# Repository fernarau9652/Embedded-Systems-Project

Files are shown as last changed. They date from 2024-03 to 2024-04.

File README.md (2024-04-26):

# Digital and Analog Synthesizer with adjustable Frequency Scaling
ECE 5780/6780 Mini-Project for SPRING 2024 \
Team Members: Chase Griswold (6780), Fernando Araujo (6780), Alex Baret (5780), Vincent Banh (5780)

Official Documentation with wire diagrams, schematics, and flow charts can be found here (NOTE: Figures mentioned in the README pertain to the figures in the documentation listed): \
./Documentation/6780_CircuitDesign_DDS_REV-A_Final.pdf

This is the path to the finalized project folder for this project: \
./STM32/5780-6780-Final-Project3/  (Other files are previous revisions of the project)

Documentation related to the PCB designs with BoM datasheets can be found here: \
./PCB/  ("Board EXPORTS" contain the PCB design revisions; everything else is datasheets and LBR files)

Additional code provided by Chase can be found here: \
./Chase_Mains/  (Contains code for ADC and I2C control for digital potentiometer)

## Overview
The purpose of this project is to develop a digital and analog synthesizer machine that would take both types of inputs to output a modified synthesized wave, which can be used for voice modelization in further developments of this project. \
Our goals were to utilize various embedded system applications such as:
- Designing two custom PCBs that allow for signal generation and frequency oscillator modulation using physical and digital potentiometers.
- The signal generation PCB generates three analog signals: Square, Triangle, and Sine waves. By adjusting the physical potentiometer, the signal's frequency can be adjusted.
- The frequency oscillator PCB generates a square wave, whose frequency can be adjusted via the I2C digital potentiometer or photoresistor (the photoresistor was extra but cool to have).
- Implementing ADC through the signal generation PCB, sampling each signal through the STM32, and outputting the waves through the Analog Discovery 2 (AD2) device.
- Implementing DAC by configuring the CubeMX project by instantiating timer 7 (TIM7) to clock at a sampling rate of 42 kHz, then using DMA to store the signal to be output again. In this section, we implemented signal addition synthesis to describe how the output signal would look like if two more signals were added to the initial wave.
- I2C and USART communication that changes a signal's frequency from the frequency oscillator PCB where the user interfaces with putty to change the resistance from the I2C digital potentiometer, therefore changing frequency. This section of the project accounts for frequency modulation.
- USART uses interrupts to wait for the user's numerical input (integers from 0 to 255), then delivers the commands to the MCU and out to the I2C-controlled digital potentiometer on the frequency oscillating wave.

Analog waveforms may be generated with two custom PCBs designed specifically for this project. One PCB generates a square wave with its frequency variation controlled via an I2C-controlled digital potentiometer. 

The other PCB is designed to emit analog waveforms and may be configured to generate a square wave, a triangle wave, or a sine wave using LM741 Operational Amplifiers. Waveforms from the second PCB may be sampled using the STM32's onboard ADC. 

Separate from the custom-PCB waveform generation, TIM7 (a timer onboard the STM32) consisting of a 16-bit auto-reload counter driven by a programmable
prescaler, a direct memory access controller (DMA onboard the STM32) used to perform programmable data transfers between memory-mapped peripherals, and a digital-to-analog converter (DAC onboard the STM32) have been utilized to implement digital signal synthesis.

#### Target Hardware Platform(s) ####
- STM32F072 MCU
- Function Generator PCB (Fig. 1)
- I2C Frequency Oscillator PCB (Fig. 3)
- FT232RL chip for USB/USART communication
#### Development Tools ####
- μVision Kiel IDE
- Diligent Waveforms 
#### Programming Languages ####
- C

## Features
- Output analog sine waves using TIM7, DMA, and DAC to PA4
- Square Wave Function Generator PCB that uses an LM324N and a DS18030 Digital Potentiometer
- Control the frequency of the I2C-controlled DS18030 Potentiometer through a PuTTy interface that communicates through USART
- Function Generator PCB utilizing LM741 Operational Amplifiers to generate square, triangle, and sine waves

## Getting Started
1) Acquire an ADC for waveform analysis
2) Diligent Waveforms 
3) USB/USART chip
4) μVision Kiel IDE
5) PuTTY
6) I2C Frequency Oscillator PCB (Fig. 4)
7) Function Generator PCB (Fig. 2)
8) Follow the test setup in Fig. 5 (NOTE: an additional connection from the PC to USART to STM32 is missing from the layout.)

### Installation
The STM32 pinout (Fig. 6):
- PB14 - SDA (I2C)
- PB13 - SCL (I2C)
- PB10 - TX (USART)
- PB11 - RX (USART)
- PC3 - 12-bit ADC input
- PA4 - 12-bit DAC output (forgot to add to the wire diagram)

Connect the TX pin to RX on your USB to TTL UART device and RX to TX. This enables serial console control of the project.\
The SDA and SCL must then be connected to the I2C digital potentiometer PCB's SDA and SCL pins. Pull-up resistors are not needed, as the board has built-in pull-ups.

Alternately, PA4 may be directly connected to an oscilloscope or output device to take advantage of the internal function generation of the project.

## Usage
Usage in all cases save for the UART-controlled digital potentiometer functionality is plug-and-play. There is no need for user input beyond physical adjustments of potentiometers or the operation of the photoresistor.

When operating over UART, the initial connection once the microcontroller has been reset will result in the message "Waiting for USART input. Please enter a number between 0 and 255." being printed to the terminal. This message is intended to be self-explanatory, and an input sanitation/verification system has been implemented to reject any other inputs beyond this range of values.

Due to an issue regarding the input system, it may occasionally be necessary to press the enter key multiple times to receive a response from the microcontroller. Only do this after entering the full value intended.

To use the function generator circuit,  connect an oscilloscope or an ADC to the respective op-amp that generates the desired waveform (square, sawtooth, sine).

To modulate a digital signal wave using additive synthesis, the code allows users to add two Sine waves of different frequencies, takes the average between the values, and then buffers the signals to the intended 12-bit resolution for the output. 

Users may adjust FREQ1 and FREQ2 to whatever musical note frequency they choose. The code will adjust the additive sine signals to the original output signal of 420 Hz and then output the final product through PA4. Images of sample waves simulated in this project can be seen here: \
./Documentation/DAC_waves/

## Architecture
The documentation listed above contains all architecture-related diagrams for this project. Design specifications for the PCBs, BoM, wire diagrams, schematics, and flow charts are also included.

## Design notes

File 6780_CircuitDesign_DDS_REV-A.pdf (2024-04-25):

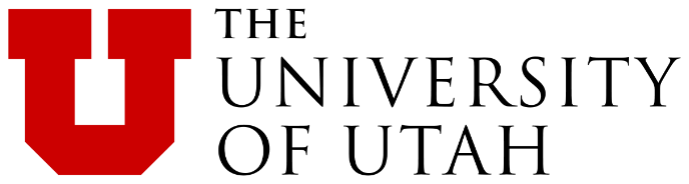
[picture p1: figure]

Chase Griswold. ECE 6780 - Embedded Systems, Spring 2024, University of Utah

### Document Stakeholders

(THESE NAMES ARE FOR INFORMATION ONLY)

PROGRAM / COURSE NUMBER

M.S. ECE: Embedded Systems 6780

Author | Chase Griswold

University of Utah

201 Presidents' Cir

Salt Lake City, Utah 84112

Design Engineer | Chase Griswold
Approver | Fernando Araujo
Approver | Vincent Banh
Approver | Alex Baret

BASELINE
Current

DATE
25 APR 2024

## Detailed Development Specification for the Function Generator and I2C Frequency Oscillator Circuits

Document: DDS | DDS for the Function Generator / I2C Frequency Oscillator
25 APR 2024 | Rev A | Page 2 of 20

This Page Intentionally Left Blank

25 APR 2024 | Rev A | Page 3 of 20
| | TABLE OF CONTENTS
Paragraph | Title | Page

25 APR 2024 | Rev - | Page 4 of 20

1 [-] INTRODUCTION

1.1 [-] Identification

This is a Detailed Development Specification document for the two PCBs/Circuits designed for the 6780 Embedded Systems final Project.
1) Function Generator Circuit Utilizing LM741 Operational Amplifiers.
2) Square Wave Function Generator Using LM324N and DS18030 Digital Potentiometer

1.2 [-] Function Generator (Overview)

This technical specification details the construction and operation of a function generator circuit that employs three LM741 operational amplifiers to produce square, triangle, and sine waveforms. The LM741 operational amplifier is a single, versatile, and reliable component used in various analog circuits, replacing the LM324 for this specific design. The circuit is capable of generating multiple waveforms with adjustments for frequency and amplitude, making it suitable for a wide range of applications. A schematic of the Function Generator can be seen in Figure 1.

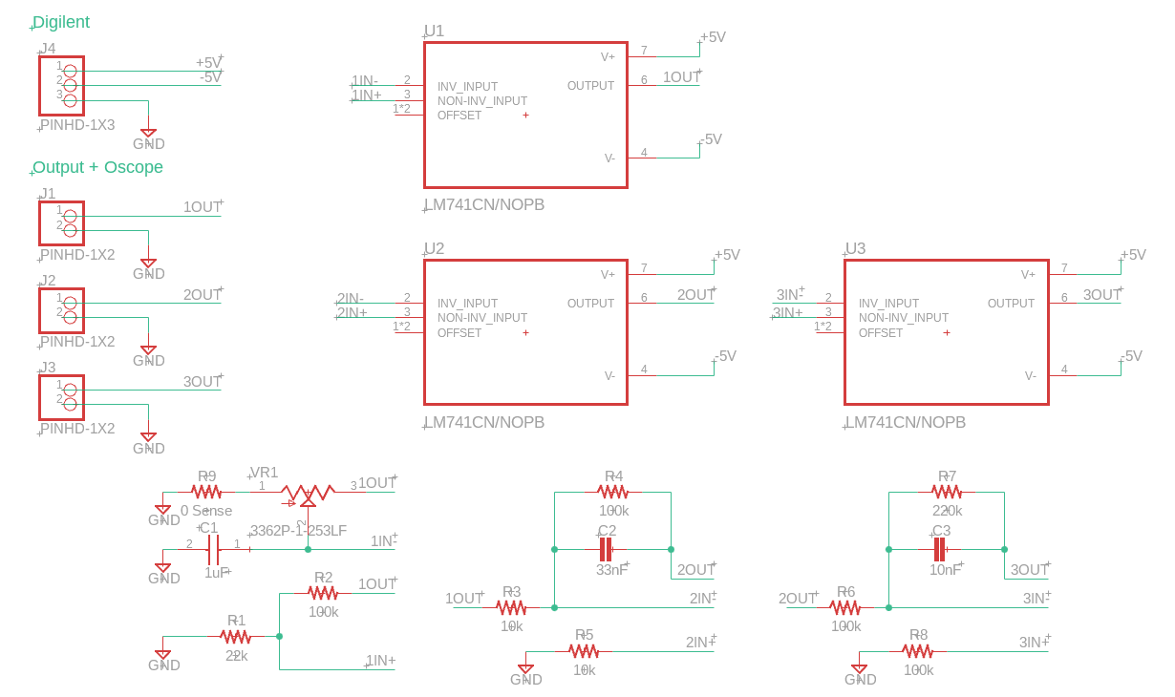
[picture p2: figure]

Figure 1 [-] Function Generator Circuit Utilizing LM741 Operational Amplifier

1.2.1 [-] External Interface Definition (Function Generator)

The PCB is shown in Figure 2, and the electrical interfaces are outlined in Table 1.

25 APR 2024 | Rev - | Page 5 of 20

Table 1 [-] Function Generator Electrical Interface

Module/CCA Ref Des | Connector Name | Connector Type | Mating Connector Type
J1 | Square Wave Output / GND | PINH Male | PINH Female
J2 | Triangle Wave Output / GND | PINH Male | PINH Female
J3 | Sine Wave Output / GND | PINH Male | PINH Female
J4 | ±5V Power Supply / GND | PINH Male | PINH Female

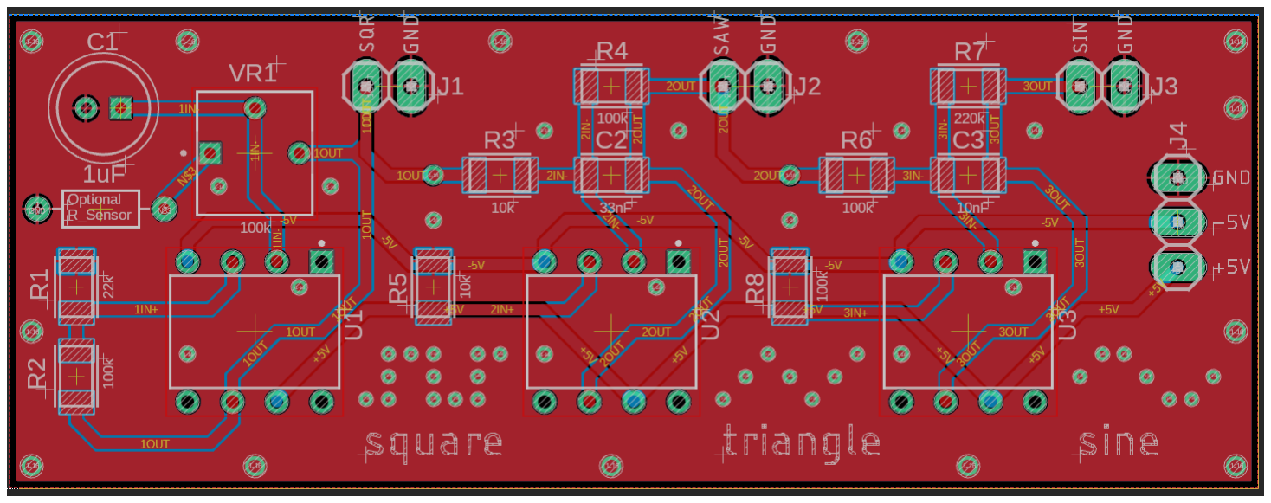
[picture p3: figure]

Figure 2 [-] Function Generator PCB

1.2.2 [-] Function Generator Operational Definitons

The LM741 operational amplifiers are biased with a dual-supply voltage of +5V and -5V, ensuring a broad signal swing range. The offset null pin of the LM741 is not utilized in this configuration. The first LM741 operational amplifier is configured to generate a square wave, which is then fed into a second LM741 configured as an integrator circuit to produce a triangle wave. This triangle wave is subsequently processed by another LM741 configured as an integrator circuit to output a sine wave. (Technically, the sine wave is formed of a parabolic voltage rise and fall, and then that parabolic voltage output is inverted, so it’s not truly a continuous sine wave).

Power is supplied to the circuit through the LM741’s power supply pins, accommodating a range from +5V to +15V for the positive supply and -5V to -15V for the negative supply. This power configuration ensures sufficient operation of the circuit across its functionalities.

Frequency modulation is achieved through a 100KΩ potentiometer, allowing for user control over the output signal's frequency. This potentiometer, in conjunction with the specific resistor and capacitor values, provides a wide range of frequency adjustments, emulating the flexibility of a standard function generator.

Amplitude adjustment can be easily implemented by varying the voltage from the DC power supply or, if powered by batteries, by adding a small-valued potentiometer (200Ω-500Ω) for voltage adjustment. This feature enhances the circuit's utility by allowing for precise control over the signal amplitude, accommodating various testing and measurement needs.

In summary, this function generator circuit, designed with LM741 operational amplifiers, offers the generation of square, triangle, and sine waveforms with adjustable frequency and amplitude. The circuit's design and component selection cater to a an excellent educational tool when considering the addition of probing points for each waveform, whereby they can be output onto an oscilloscope or sampled with an ADC.

25 APR 2024 | Rev - | Page 6 of 20

1.2.3 [A] Function Generator BOM

Table 2 [A] Function Generator BOM
Value | Type | QTY | NOTES
LM741 | IC (Amplifier) | 3
10KΩ | Resistor SMD | 2
100KΩ | Resistor SMD | 4
22KΩ | Resistor SMD | 1
220KΩ | Resistor SMD | 1
1μF | Capacitor Polarized Through-Hole | 1
1uF (REV A CHANGE) | Capacitor SMD | 1
100nF (REV A CHANGE) | Capacitor SMD | 1
N/A | PINHEADER | 10
100KΩ | Potentiometer | 1

1.3 [-] I2C Frequency Oscillator Overview

This technical specification details the construction and operation of an I2C controlled frequency oscillator circuit that employs an LM324N operational amplifier to produce a square waveform whose frequency can be adjusted via an I2C interfaced Digital Potentiometer (DS18030-100+). This is ostensibly a simpler take on the Function Generator circuit described in Section 1.2, where the potentiometer on that circuit is replaced with the DS18030-100+ I2C digital potentiometer and only the square wave is generated. A schematic of the I2C Frequency Oscillator can be seen in Figure 3.

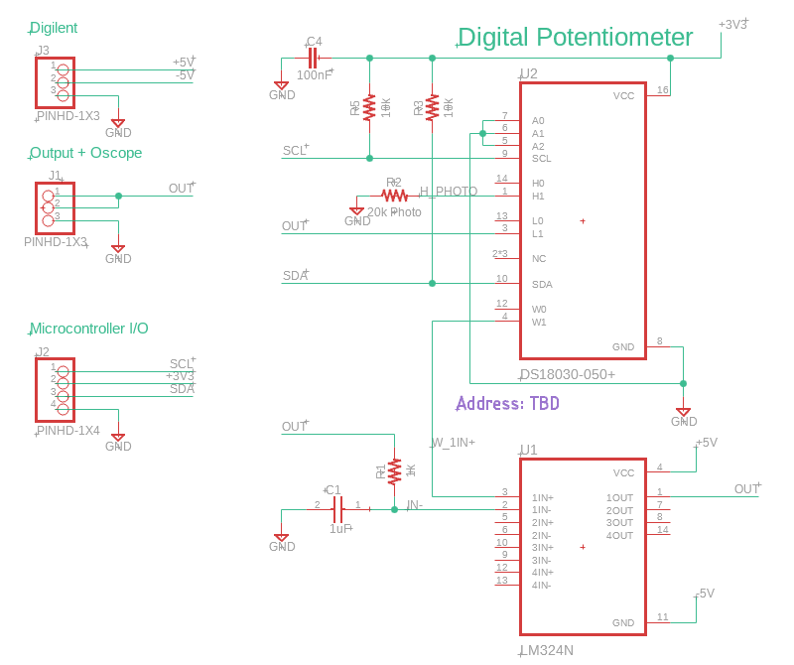
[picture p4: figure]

Figure 3 [-] I2C Frequency Oscillator Schematic

25 APR 2024 | Rev - | Page 7 of 20

1.3.1 [-] External Interface Definition (I2C Frequency Oscillator)

The I2C Frequency Oscillator PCB is shown in Figure 4, and the electrical interfaces are outlined in .

Table 3 [-] I2C Frequency Oscillator Electrical Interfae

Module/CCA Ref Des | Connector Name | Connector Type | Mating Connector Type
J1 | Square Wave Output / GND | PINH Male | PINH Female
J2 | I2C CMD/STS – V / GND | PINH Male | PINH Female
J3 | ±5V Power Supply / GND | PINH Male | PINH Female

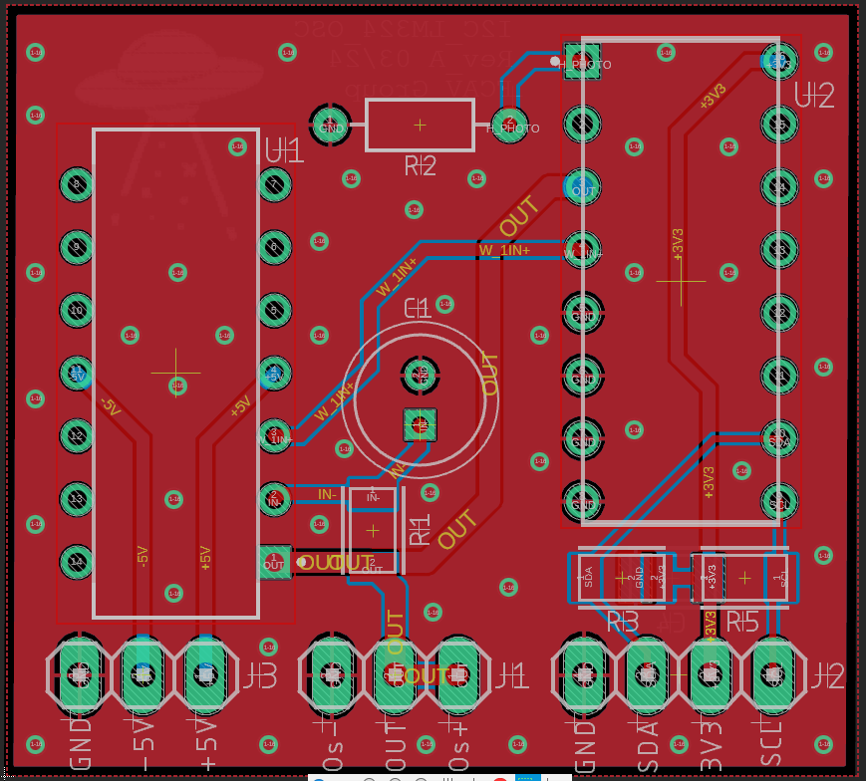
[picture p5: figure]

Figure 4 [-] I2C Frequency Oscillator PCB

25 APR 2024 | Rev - | Page 8 of 20

### 1.3.2 I2C Frequency Oscillator Operational Definitons

The circuit employs one operational amplifier within the LM324N chip to generate the square wave. Power is supplied to the LM324N with +5V and -5V to ensure a broad output swing. The frequency adjustment is facilitated by the DS18030-100+ digital potentiometer, which offers 256 tap points over a 100KΩ range, allowing for fine-tuning of the square wave's frequency. This digital potentiometer is controlled via an I2C interface, providing a way to adjust the function generator's output without manual intervention.

1.3.3 [-] I2C Frequency Oscillator BOM

Table 4 [-] I2C Frequency Oscillator BOM
Value | Type | QTY | NOTES
LM324N | IC/Amplifier | 1
DS18030-100+ | IC/ Digital Potentiometer | 1
10KΩ | Resistor | 2
1KΩ | Resistor | 1
20KΩ | Photo Resistor | 1 | optional
220KΩ | Resistor | 1
1μF | Capacitor / Polarized Through-Hole | 1
100nF | Capacitor / SMD | 1
100KΩ | Potentiometer | 1

1.4 [-] Referenced Items

Table 5 [-] Referenced Items

Document | Title
LM324N | Datasheet
LM741 | Datasheet
DS18030-100+ | Datasheet

25 APR 2024 | Rev - | Page 9 of 20

2 [-] TEST RESOURCES AND SETUP

2.1 [-] Test Resources

Table 6 lists the needed resources (or equivalent) for completing the design and scope of this part of the project. An STM32 Discovery Kit provides a versatile development platform for prototyping and testing the designs. Keil µVision IDE is an essential tool for writing, compiling, and debugging the microcontroller code, offering a user-friendly interface and powerful features that streamline the development process. To complement these resources, the Digilent Analog Discovery 2 serves as an invaluable tool for analyzing the electrical characteristics of the circuits. This multi-function instrument can act as an oscilloscope, function generator, power supply, and more.

Table 6 [-] Test Resources
Name | Model | Description | Qty | Manufacturer | Notes
Digilent Analog Discovery 2 | 2 | Signal/Logic Analyzer, Power Supply | 1 | Digilent
STM32 discovery kit STM32F072x8/xB | STM32F07 2x8/xB | Embedded Systems Application Development Board | 1 | STMicroelectronics
Keil µVision IDE | | IDE for programming the microcontroller | | Keil
PC | | Standard Issue Lab PC | 1
Misc. Cables | Various | Power/CMD/STS/Oscill oscope | | | Cables as needed
Misc. Hardware | Various | Multi-meter, etc… | | | General lab items as needed

2.2 [A] Test Setup

Connect the PCBs to the STM32 and Digilent AD2 in accordance with (IAW) Figure 5.

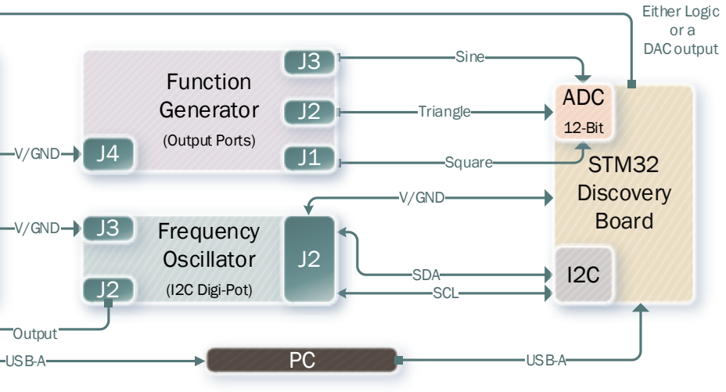
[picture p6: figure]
STM32 Discovery Board Frequency; Oscillator; (I2C Digi-Pot); Sine; SDA SCL; Square; ADC; 12-Bit; Function Generator; (Output Ports); Triangle; Either Logic or a DAC output; Output; V/GND; USB-A

Figure 5 [-] Test Setup for the Circuit Design Portion

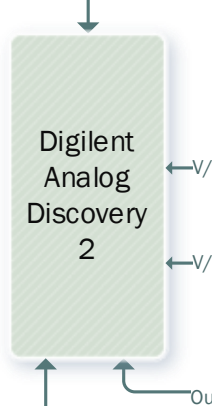
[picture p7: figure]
Digilent Analog Discovery 2
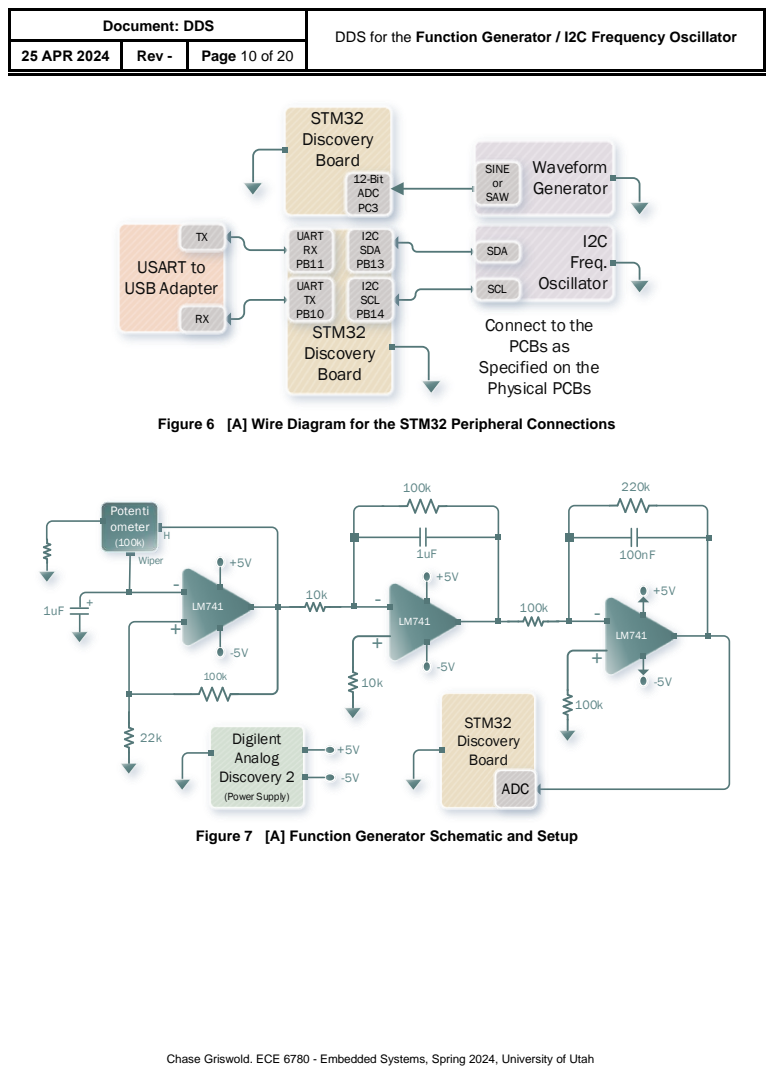
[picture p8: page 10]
25 APR 2024; Rev -; Page 10 of 20; STM32 Discovery Board; I2C SDA PB13; 12-Bit ADC PC3; I2C SCL PB14; I2C Freq. Oscillator; UART RX PB11; UART TX PB10; USART to USB Adapter; Waveform Generator; SDA; SCL; SINE or SAW; Potenti ometer; Wiper; Digilent Analog Discovery 2; (Power Supply); ADC

Connect to the
PCBs as
Specified on the
Physical PCBs

Figure 6 [A] Wire Diagram for the STM32 Peripheral Connections

Figure 7 [A] Function Generator Schematic and Setup

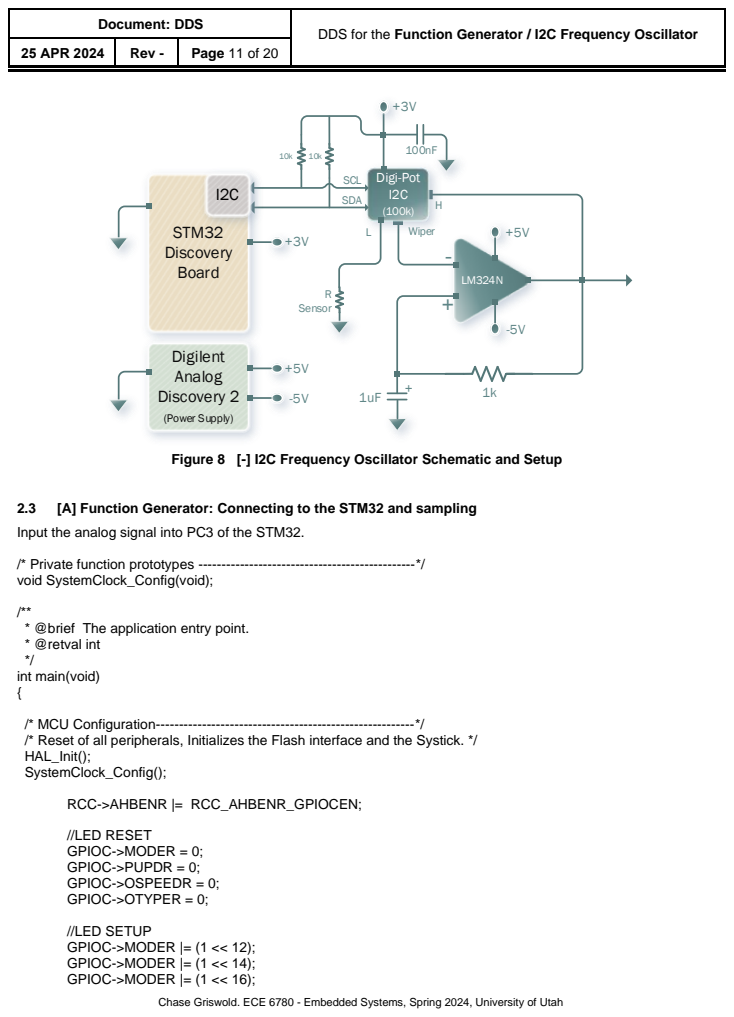
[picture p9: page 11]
25 APR 2024; Rev -; Page 11 of 20; SCL; SDA; Digi-Pot I2C; Wiper; R Sensor; Digilent Analog Discovery 2; (Power Supply); RCC->AHBENR |= RCC_AHBENR_GPIOCEN;; //LED RESET GPIOC->MODER = 0; GPIOC->PUPDR = 0; GPIOC->OSPEEDR = 0; GPIOC->OTYPER = 0;; //LED SETUP GPIOC->MODER |= (1 << 12); GPIOC->MODER |= (1 << 14); GPIOC->MODER |= (1 << 16);

STM32
Chase Griswold. ECE 6780 - Embedded Systems, Spring 2024, University of Utah +5V
Discovery
Board

Figure 8 [-] I2C Frequency Oscillator Schematic and Setup

2.3 [A] Function Generator: Connecting to the STM32 and sampling
Input the analog signal into PC3 of the STM32.

/* Private function prototypes -----------------------------------------------*/
void SystemClock_Config(void);

* @brief The application entry point.
* @retval int
int main(void)

/* MCU Configuration--------------------------------------------------------*/
/* Reset of all peripherals, Initializes the Flash interface and the Systick. */
HAL_Init();
SystemClock_Config();

25 APR 2024 | Rev - | Page 12 of 20

GPIOC->MODER |= (1 << 18);

//Set GPIOC low
GPIOC->ODR = 0;

//Set PC3 to Analog mode. (Connects to ADC_IN13) GPIOC->MODER |= (3 << 6);

// Enable the ADC1 in the RCC peripheral.
RCC->APB2ENR |= RCC_APB2ENR_ADCEN;

//Configure the ADC to 8-bit resolution, continuous conversion mode, hardware triggers //disabled (software trigger only).
ADC1->CFGR1 = 0; //Clear: Also Disables Hardware Triggers
ADC1->CFGR1 |= (1 << 13); //Continuous Conversion Mode
ADC1->CFGR1 |= (0 << 3);
ADC1->CFGR1 |= (0 << 4); //12-Bit Resolution

// Select/enable the input pin s channel for ADC conversion ADC1->CHSELR = 0; //Clear
ADC1->CHSELR |= (1 << 13); //Set Channel to ADC_IN13

// Perform a self-calibration, enable, and start the ADC. ADC1->CR = 0; //Cal
ADC1->CR |= (1 << 31); //Enable

//Wait: ADCAL: ADC calibration bit 31 = 0
while (((ADC1->CR)>>31) != 0){

}

//Zero out the ADEN
ADC1->CR |= (1 << 0); //Set ADEN

//Wait ADRDY Flag
while((ADC1->ISR && 0x1) != 1){ //ISR Bit 0: ADRDY }

//Set ADSTART: Start Conversion
ADC1->CR |= (1 << 2);

uint16_t reso = 0;

/* Infinite loop */

while (1)

{

//12-bit ADC - 4096 bits of resolution/4 LEDs = 1024

//RED 6, BLUE 7, ORANGE 8, GREEN 9

//Apply the DR stored value to a variable that can be used in the loop.

reso = ADC1->DR;

if (reso < 1024){

25 APR 2024 | Rev - | Page 13 of 20
| | GPIOC->ODR |= (1 << 6); //Red High
| | GPIOC->ODR &= ~((1 << 7) | (1 << 8) | (1 << 9));

}

else if (reso >= 1024 && reso < 2048){

| | GPIOC->ODR |= (1 << 7); // Blue High
| | GPIOC->ODR &= ~((1 << 8) | (1 << 9));

}

else if (reso >= 2048 && reso < 3072){

| | GPIOC->ODR |= (1 << 8); //Orange High
| | GPIOC->ODR &= ~(1 << 9);

}

| else {
| | GPIOC->ODR |= (1 << 9); //Green High

}

//Wait: End Sequence

while((ADC1->ISR & 0x4) != 4){

}

//Reset: FLAG after each loop

ADC1->ISR |= (1 << 2);

}

}

2.4 [A] I2C Frequency Oscillator: I2C Control with STM32

NOTE: The code below uses PB11 and PB13 for SDA and SCL respectively, versus the USART version in the wire diagram where PB11 is changed to PB14.

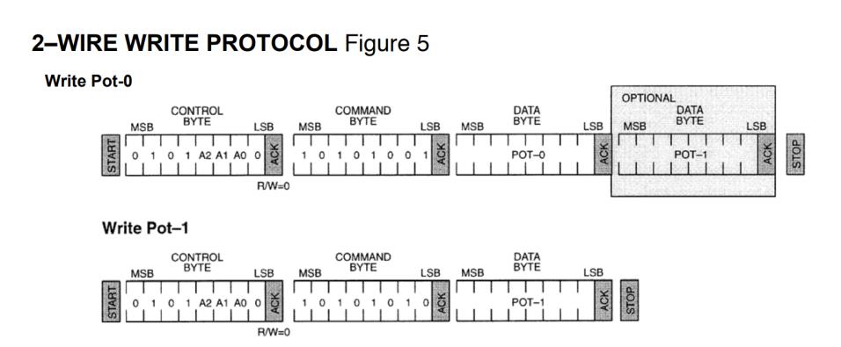
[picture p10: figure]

The PCB is hooked up to Pot-1,
USART TX from PUTTY sets the DATA BYTE values when performing the write command.

25 APR 2024 | Rev - | Page 14 of 20

Below is a simple implementation of writing to the i2c controlled Digi-Pot.

/* Includes ------------------------------------------------------------------*/
#include "main.h"

/* Private function prototypes -----------------------------------------------*/ void SystemClock_Config(void);
/* USER CODE BEGIN */

//void init_digiPot(void); //For hardcode Data Byte Version
void init_digiPot(int c);
uint8_t resist_val_data;
volatile uint8_t data;

/**
* @brief The application entry point. * @retval int
*/
int main(void)
{
/* Reset of all peripherals, Initializes the Flash interface and the Systick. */ HAL_Init();
SystemClock_Config();

/* USER CODE BEGIN SysInit */
//Enable GPIOB and GPIOC
RCC->AHBENR |= RCC_AHBENR_GPIOCEN;
RCC->AHBENR |= RCC_AHBENR_GPIOBEN; //Needed for I2C stuff

//Initialize (Clear) the GPIOB/C registers
GPIOB->OTYPER = 0;
GPIOB->MODER = 0;

//SDA Setup --------
//Initialize PB11
GPIOB->MODER |= (1 << 23); //Enable AF Mode GPIOB->OTYPER |= (1 << 11); //Open-drain

//PB11 Alternate Function AF1 select: I2C2_SDA -> AF1 of PB11 //Bits [15:12] correspond to PB11 in the register -> AF1 is 0001. GPIOB->AFR[1] |= (1 << 12);

//SCL Setup --------
// Initialize PB13
GPIOB->MODER |= (1 << 27); //Enable AF Mode GPIOB->OTYPER |= (1 << 13); //Open-drain

//PB13 Alternate Function AF5 select: I2C2_SCL -> AF5 of PB13 //Bits [23:20] correspond to PB13 in the register, -> AF5 is 0101. GPIOB->AFR[1] |= (5 << 20);

//Initialize PC0 and PB14
GPIOB->MODER |= (1 << 28); //General-Purpose Output GPIOC->MODER |= (1 << 0);
GPIOC->OTYPER = 0; //Push-pull mode.
GPIOB->ODR |= (1 << 14); //PB14 set High

25 APR 2024 | Rev - | Page 15 of 20

GPIOC->ODR |= (1 << 0); //PC0 set High

//I2C2 Peripheral RCC Enable (I2C)
RCC->APB1ENR |= RCC_APB1ENR_I2C2EN; //Clock enable

//Setting up the I2C2 Peripheral timing for SDA and SCL
//Set to 100kHz operation
I2C2->TIMINGR |= (1 << 28); //PSC = 1
I2C2->TIMINGR |= (0x4 << 20); //[23:20] SCLDEL (Data Setup Time) I2C2->TIMINGR |= (0x2 << 16); //[19:16] SDADEL (Data Hold Time) I2C2->TIMINGR |= (0xF << 8); //[15:8] SCLH (SCL High Period) I2C2->TIMINGR |= (0x13 << 0); //[7:0] SCLL (SCL Low Period)

//Enable the I2C2 Peripheral
I2C2->CR1 |= (1 << 0); //Enable (PE Bit in CR1 Register)

// Hardcodede version
//resist_val_data = 0b00010000; //Data Byte (256-bit resolution number, ~396 ohms per bit).
| data = 0;

// /* Infinite loop */ //Used to loop through all 0-255 Data Byte Values for simple visual results on an oscope.
| while (1)
{
| | init_digiPot(data); if(data<255) {

data++;
| | } else {

data = 0;
| | } HAL_Delay(25); // Delay 25ms GPIOC->ODR ^= (1 << 6);

}
}

//void write_digiPot() //If using the hardcoded version. void write_digiPot(int resist_val_data){
I2C2->CR2 = 0; //Clear to start.

//Setup: Digi-pot Address 0x28
I2C2->CR2 |= (0x28 << 1); //Digi-pot address is [7:1]

//Set # of bytes = 2 (Address + Register value). I2C2->CR2 |= (2 << 16);

//Set the RD_WRN bit to 'WRITE' operation. //Set the START bit
I2C2->CR2 &= ~(1 << 10); //Ensure 0 for write
I2C2->CR2 |= (1 << 13);

//Wait until either of the TXIS (Transmit Register Empty/Ready) //or NACKF (Slave NotAcknowledge) flags are set.

25 APR 2024 | Rev - | Page 16 of 20

//----//If the NACKF flag is set, the slave did not respond to the address frame. //----//Continue if the TXIS flag is set
while(((I2C2->ISR & 0x2) >> 1) != 1){
| | if((I2C2->ISR & 0x10) >> 4){ //NACFK flag check //Turn on LED to indicate config error GPIOC->ODR |= (1 << 6);

}
}

//Set command_byte for digi-pot TX
I2C2->TXDR = 0b10101010; // Command Byte to write to potentiometer 1.

//Wait for TXIS flag
while(((I2C2->ISR & 0x2) >> 1) != 1){
| | if((I2C2->ISR & 0x10) >> 4){ //NACFK flag check //Turn on LED to indicate config error GPIOC->ODR |= (1 << 6);

}
}

//Set data_byte for digi-pot TX I2C2->TXDR = resist_val_data;

//Wait for TC flag
while(((I2C2->ISR & 0x40) >> 6) != 1){

}

//STOP bit: Release the I2C bus I2C2->CR2 |= (1 << 14);
}

Where resist_val_data is some 8-bit value written to the Data Byte of the digital potentiometer, with each 0-255 step value corresponding to ~390 ohms out of 100k ohms.

25 APR 2024 | Rev - | Page 17 of 20

3 [-] COMPONENT DESCRIPTIONS

3.1 [-] Amplifiers

3.1.1 [-] LM741

The LM741 is a classic operational amplifier (op-amp) integrated circuit known for its versatile performance in analog circuit applications. Featuring a single op-amp configuration, it offers reliable amplification and signal processing capabilities. With its wide supply voltage range and compatibility with both single and dual power supplies, the LM741 is suitable for a variety of voltage requirements in different circuit designs. This IC comes in an 8-pin DIP package, making it easy to incorporate into various electronic projects. Its straightforward pinout and simple configuration make it a popular choice for amplification, filtering, and signal conditioning tasks in electronics.

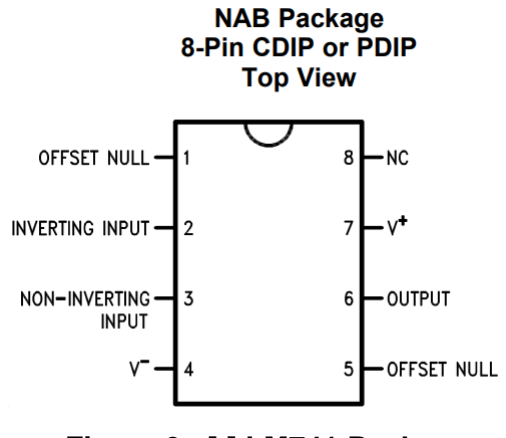
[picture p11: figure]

Figure 9 [-] LM741 Package

3.1.2 [-] LM324N

The LM324N is a widely used quad operational amplifier (op-amp) integrated circuit renowned for its versatility and reliability in analog circuit designs. With four independent op-amps housed within a single chip, it offers convenience and space-saving benefits for circuit integration. The LM324N operates over a wide range of supply voltages and is compatible with both single and dual power supplies, making it suitable for diverse voltage requirements. Its simple pinout and standard 14-pin DIP package facilitate easy incorporation into various electronic projects. Renowned for its low cost and robust performance, the LM324N is commonly utilized in amplification, filtering, signal conditioning, and other analog applications across industries.

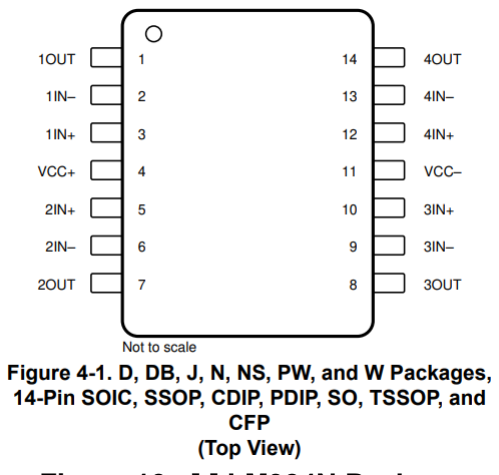
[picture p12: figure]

Figure 10 [-] LM324N Package

25 APR 2024 | Rev - | Page 18 of 20

3.2 [-] I2C

3.2.1 [-] Digital Potentiometer

Address: 0101000 (A2, A1, A0 tied to ground for the 000) - Hex: 0x28

The DS18030 is a digital potentiometer integrated circuit designed for electronic control applications. It features a 100 kΩ resistance with 256-tap resolution, allowing for precise adjustment in various circuits. This device utilizes a 2-wire serial interface, compatible with I2C communication protocols, facilitating easy integration with microcontrollers like the STM32. With its compact 16-pin DIP package, the DS18030 offers versatility and flexibility in analog circuit designs, providing a convenient solution for applications requiring digital potentiometer functionality.

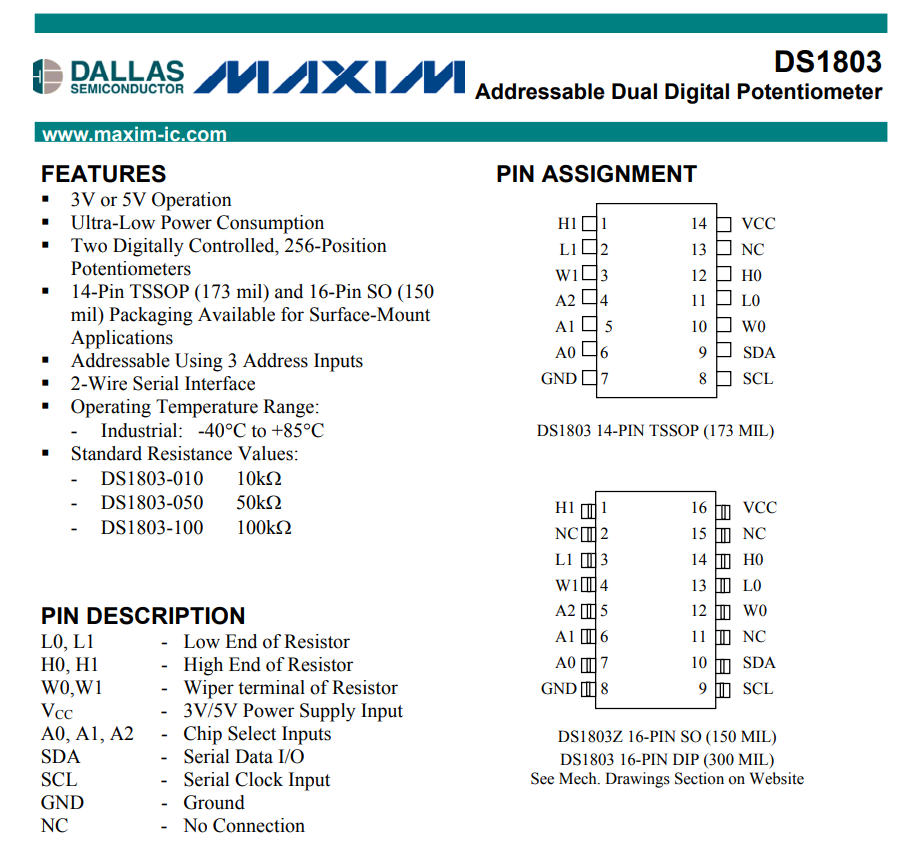
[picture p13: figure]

25 APR 2024 | Rev - | Page 19 of 20

4 [A] NOTES

We implemented an additional protocol to transmit the i2c Data Byte 8-bit digital potentiometer value over USART via PuTTY, essentially creating a GUI for us to change resistor values from.

We attached a photoresistor to the i2c Frequency Oscillator circuit to showcase how a resistive sensor can be applied to change the analog frequency, where different frequencies could correspond to different operations of a larger system. See “R-Sensor” in circuit diagram in the “setup” section.

25 APR 2024 | Rev - | Page 20 of 20

5 [-] REVISION HISTORY

Table 7 [-] Revision Table for DDS

Rev | Date | Engineer | Description
- | Mar 2023 | Chase Griswold | Initial Release
A | April 2023 | Chase Griswold | Revision A (changes to waveform generator capacitors, new schematic included in setup)

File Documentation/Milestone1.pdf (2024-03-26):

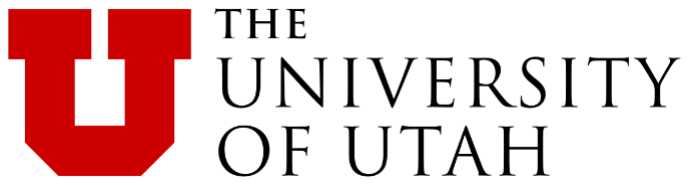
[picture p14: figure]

Chase Griswold, Fernando Araujo, Alex Baret, Vincent Banh. ECE 6780 - Embedded Systems, Spring 2024, University of Utah

### Document Stakeholders

(THESE NAMES ARE FOR INFORMATION ONLY)

PROGRAM / COURSE NUMBER

ECE: Embedded Systems 5/6780

Author | Group

University of Utah

201 Presidents' Cir

Salt Lake City, Utah 84112

Approver | Chase Griswold
Approver | Fernando Araujo
Approver | Vincent Banh
Approver | Alex Baret

BASELINE
Current

DATE
23 MAR 2024

## Digital Audio Synthesis: Milestone 1

Document: Digital Audio Synthesis

23 MAR 2024 | Rev - | Page 2 of 7

Milestone 1

This Page Intentionally Left Blank

Document: Digital Audio Synthesis

23 MAR 2024 | Rev - | Page 3 of 7

TABLE OF CONTENTS

Paragraph | Title | Page

Document: Document: Digital Audio Synthesis

23 MAR 2024 | Rev - | Page 4 of 7

1 [-] MILESTONE 1: DIGITAL AUDIO SYNTHESIS

To-do List for Project:
Explore the utilization of both hardware and software to implement an efficient, robust audio application.

PCB Design:
- See PCB Detailed Development Specification (DDS) Document.

Hardware/Software exploration:
- Implement Timers as a useful and cost-effective means to trigger actions at regular intervals.
- Implement the STM DAC for communicating with a Oscope/speaker by converting digital samples into analog signals.
- Implement DMA for data transfer with minimal processor resources, enabling simultaneous audio streaming and other processing tasks.

1.1 [-] How we will implement our design

1.1.1 [-] Timers

Embedded timers offer a plethora of advanced functionalities, rendering them highly versatile in diverse applications. Embedded timers can trigger events repeatedly through auto-reload mechanisms, facilitate both count up and count down operations, and generate rectangular waveforms, such as Pulse Width Modulation (PWM) signals. These enhanced capabilities empower embedded systems with precise timing control and signal generation, facilitating a wide range of functionalities in applications spanning from industrial automation to consumer electronics.

Timers in embedded systems are driven by the MCU clock, serving as the fundamental timing mechanism for various functionalities such as timers, ADC, DAC, and communication protocols. The clock operates at a fixed frequency, such as 8MHz, which can be divided using prescalers and auto-reload values. These divisions trigger interrupts at specified intervals, enabling actions like DMA transfers and ADC conversions. For instance, to generate audio output at a specific sample rate, we calculate the prescaler (PSC) and auto-reload (ARR) values based on the desired frequency and the clock frequency.

To achieve an output sample rate of 42 kHz with a clock speed of 8 MHz, we can calculate the prescaler (PSC) and auto-reload (ARR) values using the formula:

Given:

We can rearrange the formula to solve for PSC and ARR:

Let's start by selecting an arbitrary value for ARR (auto-reload) and then calculate PSC:

Let's choose ARR = 199.

23 MAR 2024 | Rev - | Page 5 of 7

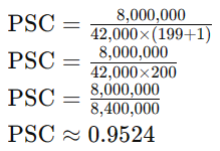
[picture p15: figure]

As PSC must be an integer value, we round it up to the nearest integer:

PSC = 1

Now that we have PSC = 1, we can calculate ARR using the same formula:

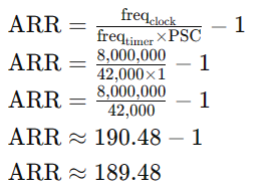
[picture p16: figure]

Again, as ARR must be an integer value, we round it to the nearest integer:

ARR = 189

Therefore, for an output sample rate of 42 kHz and a clock speed of 8 MHz, the recommended values for the prescaler (PSC) and auto-reload (ARR) registers would be PSC = 1 and ARR = 189.

A Nyquist sampling rate of 42 kHz should be suitable for our audio application due to its ability to accurately capture the frequency range of human hearing. The Nyquist theorem states that to accurately represent a signal, the sampling rate must be at least twice the highest frequency present in the signal. Since the upper limit of human hearing is generally considered to be around 20 kHz, a sampling rate of 42 kHz comfortably exceeds this threshold, allowing for accurate reproduction of audio signals without introducing aliasing or distortion. Additionally, using a sampling rate higher than the Nyquist rate ensures that the audio signal can be accurately reconstructed during playback, providing high-fidelity audio reproduction. Therefore, a Nyquist sampling rate of 42 kHz is well-suited for audio applications, providing a balance between fidelity and efficiency.

1.1.2 [-] DAC

Digital-to-analog converters (DACs) play a crucial role in bridging the gap between digital and analog domains, facilitating the conversion of binary data into electrical voltages or sound waves. In contrast to analog-to-digital converters (ADCs), which convert continuous analog signals into discrete digital values, DACs perform the inverse operation, aiming to recreate a continuous analog waveform from discrete digital samples. The output waveform's fidelity and shape are determined by the DAC implementation, with simpler DACs producing output at discrete voltage levels and more sophisticated ones employing interpolation techniques to approximate intermediate values. Despite potential inaccuracies in the interpolated values, these methods contribute to smoother output waveforms. On the STM32 platform, DAC functionality accommodates samples quantized to either 8 or 12 bits, offering flexibility in digital-to-analog conversion.

We will setup the DAC for 12-bit conversion, and expound upon what we learned in Lab 6 to implement our design.

23 MAR 2024 | Rev - | Page 6 of 7

1.1.3 [-] DMA

Direct Memory Access (DMA) is a major asset for embedded programmers. DMA proves invaluable by freeing up processor resources for other critical tasks. This includes activities like preparing subsequent buffers or rendering the graphical user interface. DMA facilitates diverse data transfers, spanning from memory-to-peripheral, peripheral-to-memory, to inter-peripheral or inter-memory transfers. For our project, we will focus on memory-to-peripheral transfers, particularly concerning DAC.

We will implement DMA to facilitate efficient data transfer from memory to the DAC. This setup will allow us to stream audio data from memory to the DAC without the need for continuous CPU intervention, thereby freeing up processing resources for other tasks.

To achieve this, we will configure the DMA controller to transfer audio samples stored in memory to the DAC peripheral. The DMA controller will handle the transfer process independently of the CPU, utilizing its own internal registers and logic to move data between memory and the DAC.

We will specify the source and destination addresses for the DMA transfer, indicating where the audio samples are stored in memory and the DAC's data register where the samples should be written. Additionally, we will configure the DMA transfer mode to double buffer (See below source text) to determine how the data transfer should be performed.

Further Reading: Baeldung: How Do DMA Controllers Work?

The following is from above source:

A critical concern arises post-buffering of a second round of data: how do we ascertain the completion of the first data transfer round? This dilemma prompts an evaluation of two synchronization methods: polling and interrupts. Polling involves blocking and awaiting the completion of the first round before initiating the next, while interrupts trigger an interrupt signal upon transfer completion, enabling the initiation of subsequent rounds within the interrupt handler. Despite their distinct advantages and considerations, both methods must ensure buffer integrity and prevent overwrites during concurrent DMA operations and buffer replenishment.

Double buffering is superior to single buffering when setting up DMA because it prevents the risk of overwriting data while it is being transferred. With single buffering, there is a possibility of data corruption or loss if new data is written to the buffer before the previous data transfer is complete. In contrast, double buffering allows one buffer to be filled with data while the other buffer is being transferred, ensuring continuous and uninterrupted data transfer without the risk of corruption or loss. This approach enhances the reliability and efficiency of DMA operations, particularly in scenarios where data integrity is critical.

23 MAR 2024 | Rev - | Page 7 of 7

2 [-] NOTES

Additional explorations (Outside the scope of this project, but this stuff came up in the reading for embedded audio applications).
- Experiment with generating stereo audio, exploring the possibility of stereo output for Channel 2.
- Explore streaming via UART with DMA support.
- Investigate the use of SIMD instructions to buffer multiple samples simultaneously.

SIMD stands for "Single Instruction, Multiple Data." It is a type of parallel computing architecture that performs the same operation on multiple data points simultaneously. SIMD instructions enable a processor to execute a single instruction across multiple data elements, allowing for efficient parallel processing of data. This technology is commonly used in multimedia applications, scientific computing, and other tasks that involve processing large amounts of data in parallel. In SIMD architecture, multiple data elements are processed in parallel using a single instruction, thereby increasing computational throughput and efficiency.

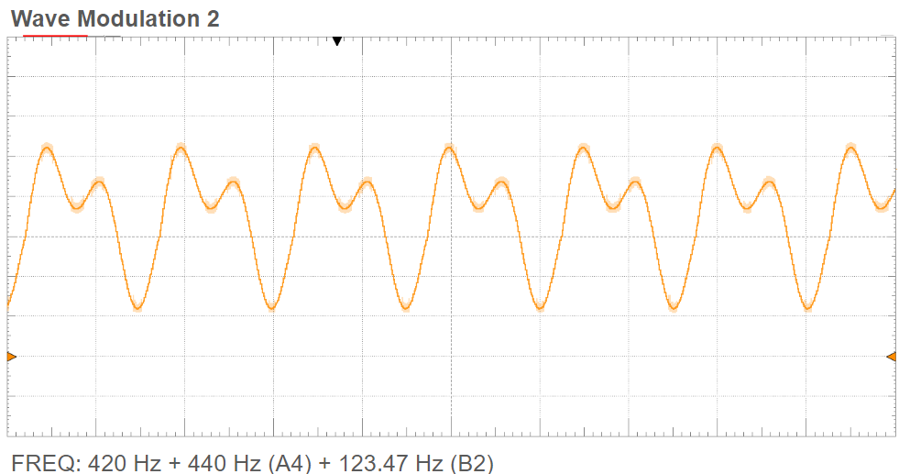
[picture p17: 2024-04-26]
Documentation/DAC_waves/wave2-modulation2.png

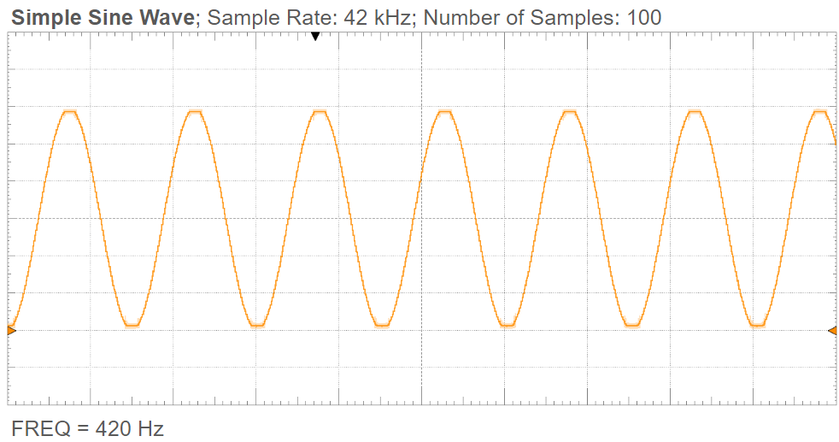
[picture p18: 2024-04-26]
Documentation/DAC_waves/wave0-420Hz.png

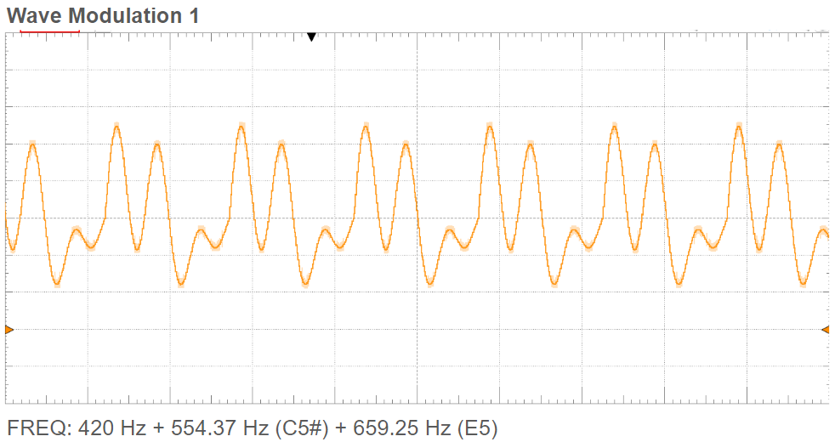
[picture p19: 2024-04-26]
Documentation/DAC_waves/wave1-modulation1.png

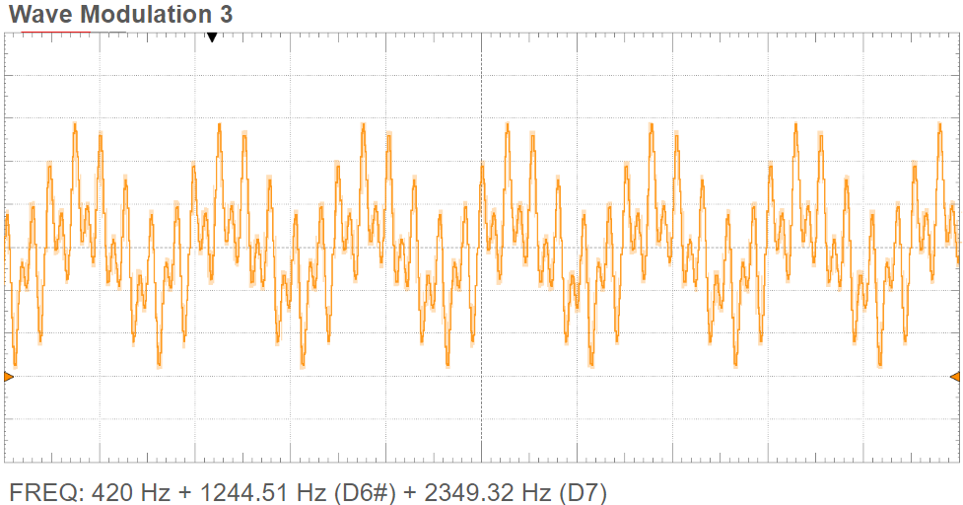
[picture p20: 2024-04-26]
Documentation/DAC_waves/wave3-modulation3.png

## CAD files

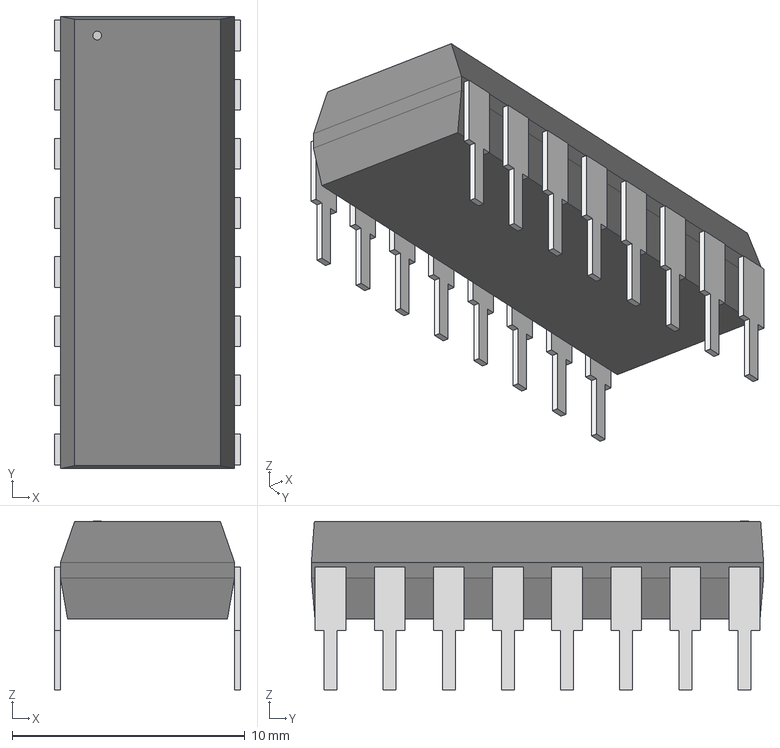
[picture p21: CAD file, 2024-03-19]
PCB/Digikey_DS1803/Digikey Version (not as goos)/DS18030_100_/Fusion360/21-0043D_16_MXM.step
7.99 x 19.4 x 7.24 mm

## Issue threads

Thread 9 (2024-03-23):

Upload PCB schematics with explanation video and/or documentation for each PCB

alex-baret, 2024-03-23:
**The purpose of this item is to make the rest of the team explicitly aware of how the PCBs work and what components are used.**

@TheMajorTechie, @fernarau9652, and I spent some time inferring how exactly the PCBs work but an explicit explanation of how the components on each board interface with each other, what the inputs and/or outputs of the PCBs are, etc. would help.

**What we've come to so far:**

1. Square Wave PCB (first one)

- Generates a square wave with digital potentiometer
- Controlled through I2C

2. Multi Analog Wave PCB (second one)

- Creates analog waveforms
- Creates square, sine, and triangle waves
- Will need to be sampled by the ADC on STM32

**Questions:**
For these questions if it's not something that has already been identified, we can make an item for it and someone on the team can pick it up.

 - For the Square Wave PCB, what would the flow of control look like? STM32 -> Square Wave PCB -> Process output of Square Wave PCB? Would the output of the square wave PCB then be returned to? The STM32? If not, what?
 - For the Square Wave PCB, does it directly generate a digital waveform? Or does it create an analog signal and then convert it? What is the form of the output (digital or analog)?
 - For the Multi Analog Wave PCB, what would the flow of control look like? STM32 says create a wave over I2C -> Multi Analog Wave PCB creates wave -> outputs analog wave to STM32 -> STM32's ADC samples it -> **final output is what**?

chasegriswold, 2024-03-24:
PCB Documentation uploaded in latest commit (See Circuit Design Commit).

Both output purely analog signals. On the I2C Frequency Oscillator PCB, we'll just be changing the frequency of the analog signal being produced via I2C on the STM32. For the Function Generator (waveform generator), we will be sampling that with the ADC and turning it into a digital signal. We can output the ADCs read directly to the logic analyzer of our Digilent analog discovery 2 devices, or we can feed it into a DAC on the STM and then feed it into the Oscilloscope of the AD2, either way.

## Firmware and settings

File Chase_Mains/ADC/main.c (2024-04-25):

///* USER CODE BEGIN Header */
///**
//  ******************************************************************************
//  * @file           : main.c
//  * @brief          : Main program body
//  ******************************************************************************
//  * @attention
//  *
//  * Copyright (c) 2024 STMicroelectronics.
//  * All rights reserved.
//  *
//  * This software is licensed under terms that can be found in the LICENSE file
//  * in the root directory of this software component.
//  * If no LICENSE file comes with this software, it is provided AS-IS.
//  *
//  ******************************************************************************
//  */
///* USER CODE END Header */
///* Includes ------------------------------------------------------------------*/
//#include "main.h"

///* Private includes ----------------------------------------------------------*/
///* USER CODE BEGIN Includes */

///* USER CODE END Includes */

///* Private typedef -----------------------------------------------------------*/
///* USER CODE BEGIN PTD */

///* USER CODE END PTD */

///* Private define ------------------------------------------------------------*/
///* USER CODE BEGIN PD */

///* USER CODE END PD */

///* Private macro -------------------------------------------------------------*/
///* USER CODE BEGIN PM */

///* USER CODE END PM */

///* Private variables ---------------------------------------------------------*/
//ADC_HandleTypeDef hadc;

///* USER CODE BEGIN PV */

///* USER CODE END PV */

///* Private function prototypes -----------------------------------------------*/
//void SystemClock_Config(void);
//static void MX_GPIO_Init(void);
//static void MX_ADC_Init(void);
///* USER CODE BEGIN PFP */

///* USER CODE END PFP */

///* Private user code ---------------------------------------------------------*/
///* USER CODE BEGIN 0 */

///* USER CODE END 0 */

///**
//  * @brief  The application entry point.
//  * @retval int
//  */
//int main(void)
//{
//  /* USER CODE BEGIN 1 */

//  /* USER CODE END 1 */

//  /* MCU Configuration--------------------------------------------------------*/

//  /* Reset of all peripherals, Initializes the Flash interface and the Systick. */
//  HAL_Init();

//  /* USER CODE BEGIN Init */

//  /* USER CODE END Init */

//  /* Configure the system clock */
//  SystemClock_Config();

//  /* USER CODE BEGIN SysInit */

//  /* USER CODE END SysInit */

//  /* Initialize all configured peripherals */
//  MX_GPIO_Init();
//  MX_ADC_Init();
//  /* USER CODE BEGIN 2 */

//  /* USER CODE END 2 */

//  /* Infinite loop */
//  /* USER CODE BEGIN WHILE */
//  while (1)
//  {
//    /* USER CODE END WHILE */

//    /* USER CODE BEGIN 3 */
//  }
//  /* USER CODE END 3 */
//}

///**
//  * @brief System Clock Configuration
//  * @retval None
//  */
//void SystemClock_Config(void)
//{
//  RCC_OscInitTypeDef RCC_OscInitStruct = {0};
//  RCC_ClkInitTypeDef RCC_ClkInitStruct = {0};

//  /** Initializes the RCC Oscillators according to the specified parameters
//  * in the RCC_OscInitTypeDef structure.
//  */
//  RCC_OscInitStruct.OscillatorType = RCC_OSCILLATORTYPE_HSI|RCC_OSCILLATORTYPE_HSI14;
//  RCC_OscInitStruct.HSIState = RCC_HSI_ON;
//  RCC_OscInitStruct.HSI14State = RCC_HSI14_ON;
//  RCC_OscInitStruct.HSICalibrationValue = RCC_HSICALIBRATION_DEFAULT;
//  RCC_OscInitStruct.HSI14CalibrationValue = 16;
//  RCC_OscInitStruct.PLL.PLLState = RCC_PLL_NONE;
//  if (HAL_RCC_OscConfig(&RCC_OscInitStruct) != HAL_OK)
//  {
//    Error_Handler();
//  }

//  /** Initializes the CPU, AHB and APB buses clocks
//  */
//  RCC_ClkInitStruct.ClockType = RCC_CLOCKTYPE_HCLK|RCC_CLOCKTYPE_SYSCLK
//                              |RCC_CLOCKTYPE_PCLK1;
//  RCC_ClkInitStruct.SYSCLKSource = RCC_SYSCLKSOURCE_HSI;
//  RCC_ClkInitStruct.AHBCLKDivider = RCC_SYSCLK_DIV1;
//  RCC_ClkInitStruct.APB1CLKDivider = RCC_HCLK_DIV1;

//  if (HAL_RCC_ClockConfig(&RCC_ClkInitStruct, FLASH_LATENCY_0) != HAL_OK)
//  {
//    Error_Handler();
//  }
//}

///**
//  * @brief ADC Initialization Function
//  * @param None
//  * @retval None
//  */
//static void MX_ADC_Init(void)
//{

//  /* USER CODE BEGIN ADC_Init 0 */

//  /* USER CODE END ADC_Init 0 */

//  ADC_ChannelConfTypeDef sConfig = {0};

//  /* USER CODE BEGIN ADC_Init 1 */

//  /* USER CODE END ADC_Init 1 */

//  /** Configure the global features of the ADC (Clock, Resolution, Data Alignment and number of conversion)
//  */
//  hadc.Instance = ADC1;
//  hadc.Init.ClockPrescaler = ADC_CLOCK_ASYNC_DIV1;
//  hadc.Init.Resolution = ADC_RESOLUTION_12B;
//  hadc.Init.DataAlign = ADC_DATAALIGN_RIGHT;
//  hadc.Init.ScanConvMode = ADC_SCAN_DIRECTION_FORWARD;
//  hadc.Init.EOCSelection = ADC_EOC_SINGLE_CONV;
//  hadc.Init.LowPowerAutoWait = DISABLE;
//  hadc.Init.LowPowerAutoPowerOff = DISABLE;
//  hadc.Init.ContinuousConvMode = DISABLE;
//  hadc.Init.DiscontinuousConvMode = DISABLE;
//  hadc.Init.ExternalTrigConv = ADC_SOFTWARE_START;
//  hadc.Init.ExternalTrigConvEdge = ADC_EXTERNALTRIGCONVEDGE_NONE;
//  hadc.Init.DMAContinuousRequests = DISABLE;
//  hadc.Init.Overrun = ADC_OVR_DATA_PRESERVED;
//  if (HAL_ADC_Init(&hadc) != HAL_OK)
//  {
//    Error_Handler();
//  }

//  /** Configure for the selected ADC regular channel to be converted.
//  */
//  sConfig.Channel = ADC_CHANNEL_0;
//  sConfig.Rank = ADC_RANK_CHANNEL_NUMBER;
//  sConfig.SamplingTime = ADC_SAMPLETIME_1CYCLE_5;
//  if (HAL_ADC_ConfigChannel(&hadc, &sConfig) != HAL_OK)
//  {
//    Error_Handler();
//  }
//  /* USER CODE BEGIN ADC_Init 2 */

//  /* USER CODE END ADC_Init 2 */

//}

///**
//  * @brief GPIO Initialization Function
//  * @param None
//  * @retval None
//  */
//static void MX_GPIO_Init(void)
//{
///* USER CODE BEGIN MX_GPIO_Init_1 */
///* USER CODE END MX_GPIO_Init_1 */

//  /* GPIO Ports Clock Enable */
//  __HAL_RCC_GPIOA_CLK_ENABLE();

///* USER CODE BEGIN MX_GPIO_Init_2 */
///* USER CODE END MX_GPIO_Init_2 */
//}

///* USER CODE BEGIN 4 */

///* USER CODE END 4 */

///**
//  * @brief  This function is executed in case of error occurrence.
//  * @retval None
//  */
//void Error_Handler(void)
//{
//  /* USER CODE BEGIN Error_Handler_Debug */
//  /* User can add his own implementation to report the HAL error return state */
//  __disable_irq();
//  while (1)
//  {
//  }
//  /* USER CODE END Error_Handler_Debug */
//}

//#ifdef  USE_FULL_ASSERT
///**
//  * @brief  Reports the name of the source file and the source line number
//  *         where the assert_param error has occurred.
//  * @param  file: pointer to the source file name
//  * @param  line: assert_param error line source number
//  * @retval None
//  */
//void assert_failed(uint8_t *file, uint32_t line)
//{
//  /* USER CODE BEGIN 6 */
//  /* User can add his own implementation to report the file name and line number,
//     ex: printf("Wrong parameters value: file %s on line %d\r\n", file, line) */
//  /* USER CODE END 6 */
//}
//#endif /* USE_FULL_ASSERT */



















/* ADC and DAC Lab (Uncomment as needed to obtain each version) */
/**CHASE GRISWOLD
  ******************************************************************************
  * @file           : main.c
  * @brief          : Main program body
  ******************************************************************************
  * @attention
  *
  * Copyright (c) 2024 STMicroelectronics.
  * All rights reserved.
  *
  * This software is licensed under terms that can be found in the LICENSE file
  * in the root directory of this software component.
  * If no LICENSE file comes with this software, it is provided AS-IS.
  *
  ******************************************************************************
  */
/* USER CODE END Header */
/* Includes ------------------------------------------------------------------*/
#include "main.h"

void SystemClock_Config(void);

/**
  * @brief  The application entry point.
  * @retval int
  */
int main(void)
{

  /* MCU Configuration--------------------------------------------------------*/
  /* Reset of all peripherals, Initializes the Flash interface and the Systick. */
  HAL_Init();
  SystemClock_Config();

//_____________________UNCOMMENT FOR ADC_SECTION____________
	RCC->AHBENR |=  RCC_AHBENR_GPIOCEN;
	
	//LED RESET
	GPIOC->MODER = 0;
	GPIOC->PUPDR = 0;
	GPIOC->OSPEEDR = 0;
	GPIOC->OTYPER = 0;
	
	//LED SETUP
	GPIOC->MODER |= (1 << 12);
	GPIOC->MODER |= (1 << 14); 
	GPIOC->MODER |= (1 << 16);
	GPIOC->MODER |= (1 << 18);
	
	//Set GPIOC low
	GPIOC->ODR = 0;
	
	//Set PC3 to Analog mode. (Connects to ADC_IN13)
	GPIOC->MODER |= (3 << 6);
	
	// Enable the ADC1 in the RCC peripheral.
	RCC->APB2ENR |= RCC_APB2ENR_ADCEN;
	
	//Configure the ADC to 8-bit resolution, continuous conversion mode, hardware triggers
	//disabled (software trigger only).
	ADC1->CFGR1 = 0; //Clear: Also Disables Hardware Triggers
	ADC1->CFGR1 |= (1 << 13); //Continuous Conversion Mode
	ADC1->CFGR1 |= (0 << 3); 
	ADC1->CFGR1 |= (0 << 4); //12-Bit Resolution
	
	// Select/enable the input pin s channel for ADC conversion
	ADC1->CHSELR = 0; //Clear
	ADC1->CHSELR |= (1 << 13); //Set Channel to ADC_IN13

	// Perform a self-calibration, enable, and start the ADC.
	ADC1->CR = 0; //Cal
	ADC1->CR |= (1 << 31); //Enable
	
	//Wait:  ADCAL: ADC calibration bit 31 = 0
	while (((ADC1->CR)>>31) != 0){
		
	}
	
	//Zero out the ADEN
	ADC1->CR |= (1 << 0); //Set ADEN
	
	//Wait ADRDY Flag
	while((ADC1->ISR && 0x1) != 1){ //ISR Bit 0: ADRDY
	}
	
	//Set ADSTART: Start Conversion
	ADC1->CR |= (1 << 2);
	
	uint16_t reso = 0;
//__________________________ADC_ABOVE_____________________




////_____________________DAC_SECTION_____________


//	//Enable GPIOA in RCC
//	RCC->AHBENR |= RCC_AHBENR_GPIOAEN;
//	
//	//Default GPIOA
//	GPIOA->MODER = 0x28000000;
//	GPIOA->OTYPER = 0;
//	GPIOA->PUPDR = 0;
//	//GPIOA->OSPEEDR;
//	
//	//Set PA4 to AF (DAC_OUT1)
//	GPIOA->MODER |= (3 << 8);
//	
//	//Enable DAC in RCC
//	RCC->APB1ENR |= RCC_APB1ENR_DACEN;
//	
//	//DAC Setup
//	//2. Set the used DAC channel to software trigger mode.
//	DAC1->CR = 0; //Clear
//	DAC1->CR |= (7 << 3); //SW Trigger Mode
//	DAC1->SWTRIGR = 0;
//	DAC1->SWTRIGR |= (1 << 0); //SW Channel 1 Trigger
//	
//	//3. Enable the used DAC channel.
//	//Enable
//	DAC1->CR |= (1 << 0);
//	
//	// Sine Wave: 8-bit, 32 samples/cycle
//	const uint8_t sine_table[32] = {127,151,175,197,216,232,244,251,254,251,244,
//	232,216,197,175,151,127,102,78,56,37,21,9,2,0,2,9,21,37,56,78,102};
//	// Triangle Wave: 8-bit, 32 samples/cycle
//	const uint8_t triangle_table[32] = {0,15,31,47,63,79,95,111,127,142,158,174,
//	190,206,222,238,254,238,222,206,190,174,158,142,127,111,95,79,63,47,31,15};
//	// Sawtooth Wave: 8-bit, 32 samples/cycle
//	const uint8_t sawtooth_table[32] = {0,7,15,23,31,39,47,55,63,71,79,87,95,103,
//	111,119,127,134,142,150,158,166,174,182,190,198,206,214,222,230,238,246};
//	// Square Wave: 8-bit, 32 samples/cycle
//	const uint8_t square_table[32] = {254,254,254,254,254,254,254,254,254,254,
//	254,254,254,254,254,254,0,0,0,0,0,0,0,0,0,0,0,0,0,0,0,0};

//	//5. In the main application loop, use an index variable to write the next value in the wave-table
//  //(array) to the appropriate DAC data register.
//	// 6. Use a 1ms delay between updating the DAC to new values

////_____________________END_DAC_SECTION_____________________



  /* Infinite loop */
  /* USER CODE BEGIN WHILE */
  while (1)
  {
		
//		//______________DAC__________________
//			for(int i = 0; i < 32; i++){
//				DAC1->DHR8R1 = sine_table[i]; //Change this line to do triangle or saw.
//				HAL_Delay(1);
//			}
//		//____________END_DAC___________________
		
				
				
				
		
		//_____________________Uncomment for ADC____________________
		//8-bit ADC - 256 bits of resolution/4 LEDs = 64
		//RED 6, BLUE 7, ORANGE 8, GREEN 9
		
		//Apply the DR stored value to a variable that can be used in the loop.	
		reso = ADC1->DR;
		
			
		if (reso < 1024){
			GPIOC->ODR |= (1 << 6); //Red High
			GPIOC->ODR &= ~((1 << 7) | (1 << 8) | (1 << 9));
		}
		else if (reso >= 1024 && reso < 2048){
			GPIOC->ODR |= (1 << 7); // Blue High
			GPIOC->ODR &= ~((1 << 8) | (1 << 9));
		}
		else if (reso >= 2048 && reso < 3072){
			GPIOC->ODR |= (1 << 8); //Orange High
			GPIOC->ODR &= ~(1 << 9);
		}
		else {
			GPIOC->ODR |= (1 << 9); //Green High
		}
		
		//Wait: End Sequence
		while((ADC1->ISR & 0x4) != 4){
			
		}
		//Reset: FLAG after each loop
		ADC1->ISR |= (1 << 2);
//________________________ADC__ABOVE_________________________________


	}
}

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


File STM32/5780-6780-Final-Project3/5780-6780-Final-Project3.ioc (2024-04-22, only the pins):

Mcu.UserName=STM32F072RBTx
PA13.Signal=SYS_SWDIO
PA14.Signal=SYS_SWCLK
PA4.Signal=COMP_DAC1_group
PC13.Signal=SYS_WKUP2

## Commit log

2024-03-19 PCB Commit - 1
    Contains the Datasheets for the ICs and also includes the Fusion360 files for the PCB designs. (there may be other PCB commits to include any relevant information.
    [21-0043D_16_MXM.step, 741_Waveform_Gen_RevA v5.brd, I2C_LM324_OSC_RevA_v10.brd]
2024-03-19 Added init STM32 files and name to README.md
2024-03-24 Documentation for the Circuit Design
    Uploading a detailed development specification for the PCBs being designed for the project, and the test setup and some steps on how we'll use them in the project.
2024-03-26 Implemented the initial peripherals for Timers, DAC, DMA, I2C, and LEDs. This is only a template for later testing.
2024-03-26 Added ADC calibration and enable in initADC()
2024-03-27 Added helper functions for I2C
2024-03-31 Added DAC sine, triangle, and sawtooth wavetables for both 128 and 64 samples per cycle.
2024-04-01 enabled the ADC and DAC clocks in RCC, ensured that the DAC signals are running smoothly
2024-04-02 Refactored main.c and added multiple functions for I2C and USART communication.
2024-04-04 USART to I2C transmission now working!
2024-04-04 Set up I2C wrapper for DS1803
    Currently ready to code with hardware
2024-04-19 Overhauled UART code to handle strings of numbers for transmission over I2C
2024-04-20 added a new project file which contains the necessary MXCube generated files for DAC to DMA conversion. Also added in the code done from the previous project
2024-04-21 i2c_code for digi-potentiometer.
    Writes all possible resistor values to the potentiometer in the infinite while loop in main function. PB11 is SDA and PB13 is SCL. PCB can source the 3V directly from the STM32. This code is to contr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
2024-04-22 got UART to I2C code transmitting and working!
2024-04-22 refactored code and added basic input sanitation to UART code
2024-04-22 added a new project file because I messed up project2 thinking I set the right DAC-DMA settings from CubeMX. Project3, should now work for everything.
2024-04-25 made sure to fix up the modulation schemes and tested for our video
    [main.c]
2024-04-25 disabled the LEDs used in the DAC2DMA function
2024-04-25 Final Documentation and Diagram Submission
    Circuit Design/Diagram implementation documentation finished, with simple code included in the documentation for the use of the i2c potentiometer and sampling the waveform generator with the ADC.
